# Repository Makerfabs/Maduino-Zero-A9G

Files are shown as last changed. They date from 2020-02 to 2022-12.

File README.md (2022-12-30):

# Maduino-Zero-A9G

```c++
/*
Version:		V1.0
Author:			Vincent
Create Date:	2022/12/30
Note:
	
*/
```
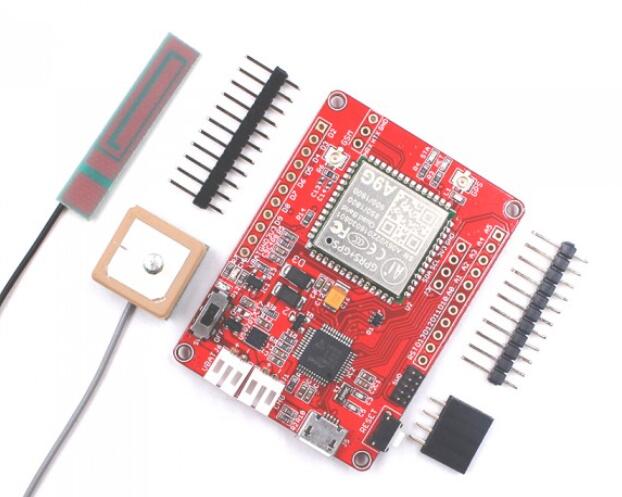
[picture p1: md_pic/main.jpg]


[toc]

# Makerfabs

[Makerfabs home page](https://www.makerfabs.com/)

[Makerfabs Wiki](https://wiki.makerfabs.com/)

# Maduino-Zero-A9G
## Intruduce

Product Link ：[Maduino Zero GPRS/GPS A9G](https://www.makerfabs.com/maduino-zero-a9g.html) 

Wiki Link : [Maduino Zero A9G](https://wiki.makerfabs.com/Maduino_Zero_A9G.html) 

Maduino Zero A9G is an IoT (Internet of things) Solution based on the 32-bit Atmel’s SAMD21 MCU and GPRS/GSM GPS module A9G. It integrates a micro Controller ATSAMD21G18, GRRS/GSM GPS module A9G, which is the upgrade version of Maduino GPRS A7, power management and storage, to make the A9G ready for a real project for IoT projects such as smart-home, outdoor monitoring, etc. The Maduino Zero A9G is based on the Arduino, users can program it with Arduino IDE, which is very easy especially suit for the none-programmers. There are also guide for users to learn how to create the first IoT project with this board, with which the starters can learn the hardware and programming skill quickly. With this board, you will easy to add text, SMS, and data to your project. It is good for your smart home project or GPS tracker and so on.

## Feature

- BAT Input Voltage: 3.4-4.2V
- ATSAMD21G18, 32-Bit ARM Cortex M0+
- Micro SIM connector
- Integrated Power Control System
- Support AT Command
- Quad-Band: 850/900/1800/1900Mz
- Support GPS
- Support GPRS data traffic, the maximum data rate, download 85.6Kbps, upload 42.8Kbps

# Code

## Compiler Options

**If you have any questions，such as how to install the development board, how to download the code, how to install the library. Please refer to :[Makerfabs_FAQ](https://github.com/Makerfabs/Makerfabs_FAQ)**

- Install board : **Arduino Zero**.
- Upload codes, select **Arduino/Genuino Zero(Native USB port)**

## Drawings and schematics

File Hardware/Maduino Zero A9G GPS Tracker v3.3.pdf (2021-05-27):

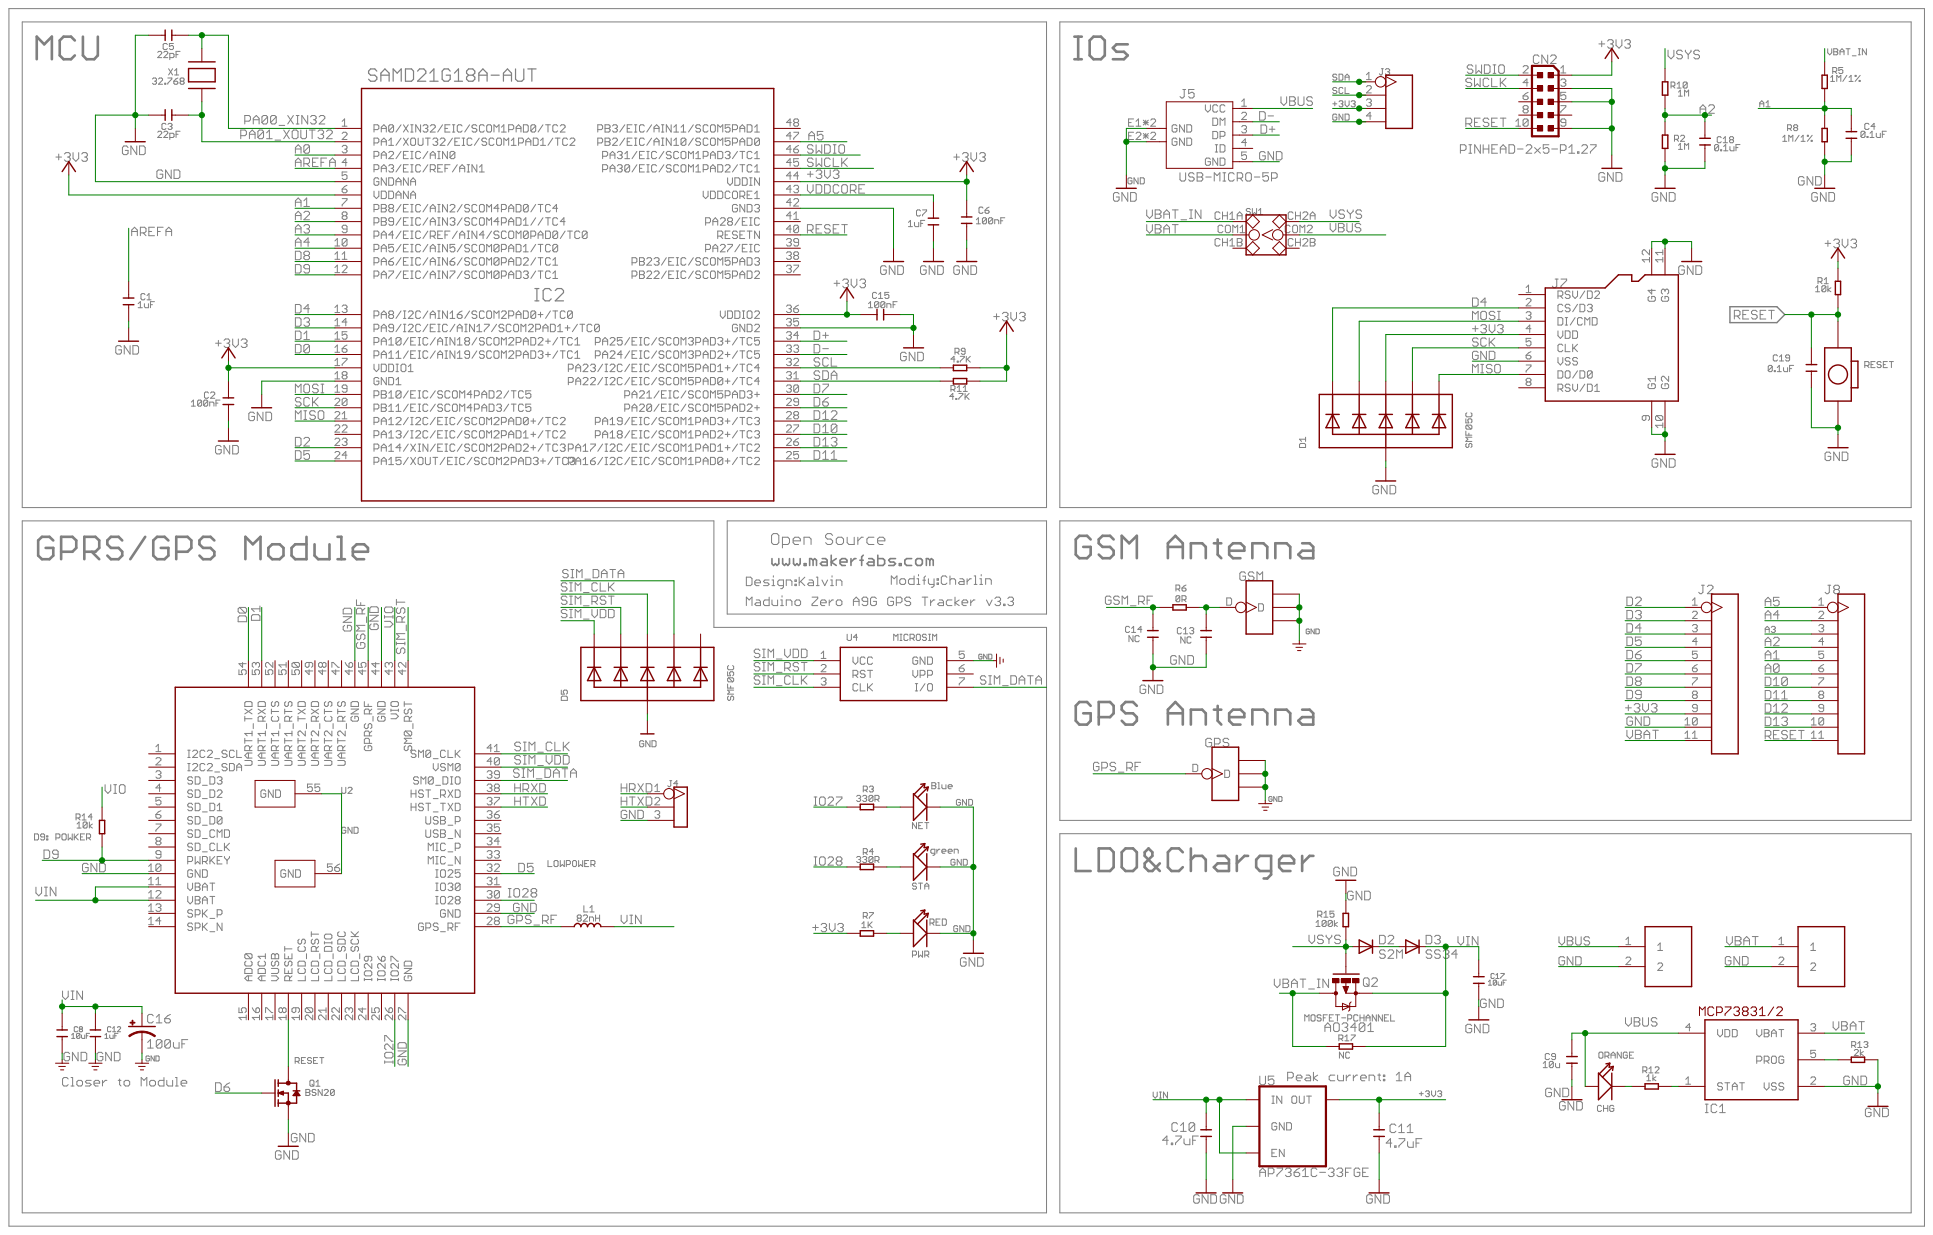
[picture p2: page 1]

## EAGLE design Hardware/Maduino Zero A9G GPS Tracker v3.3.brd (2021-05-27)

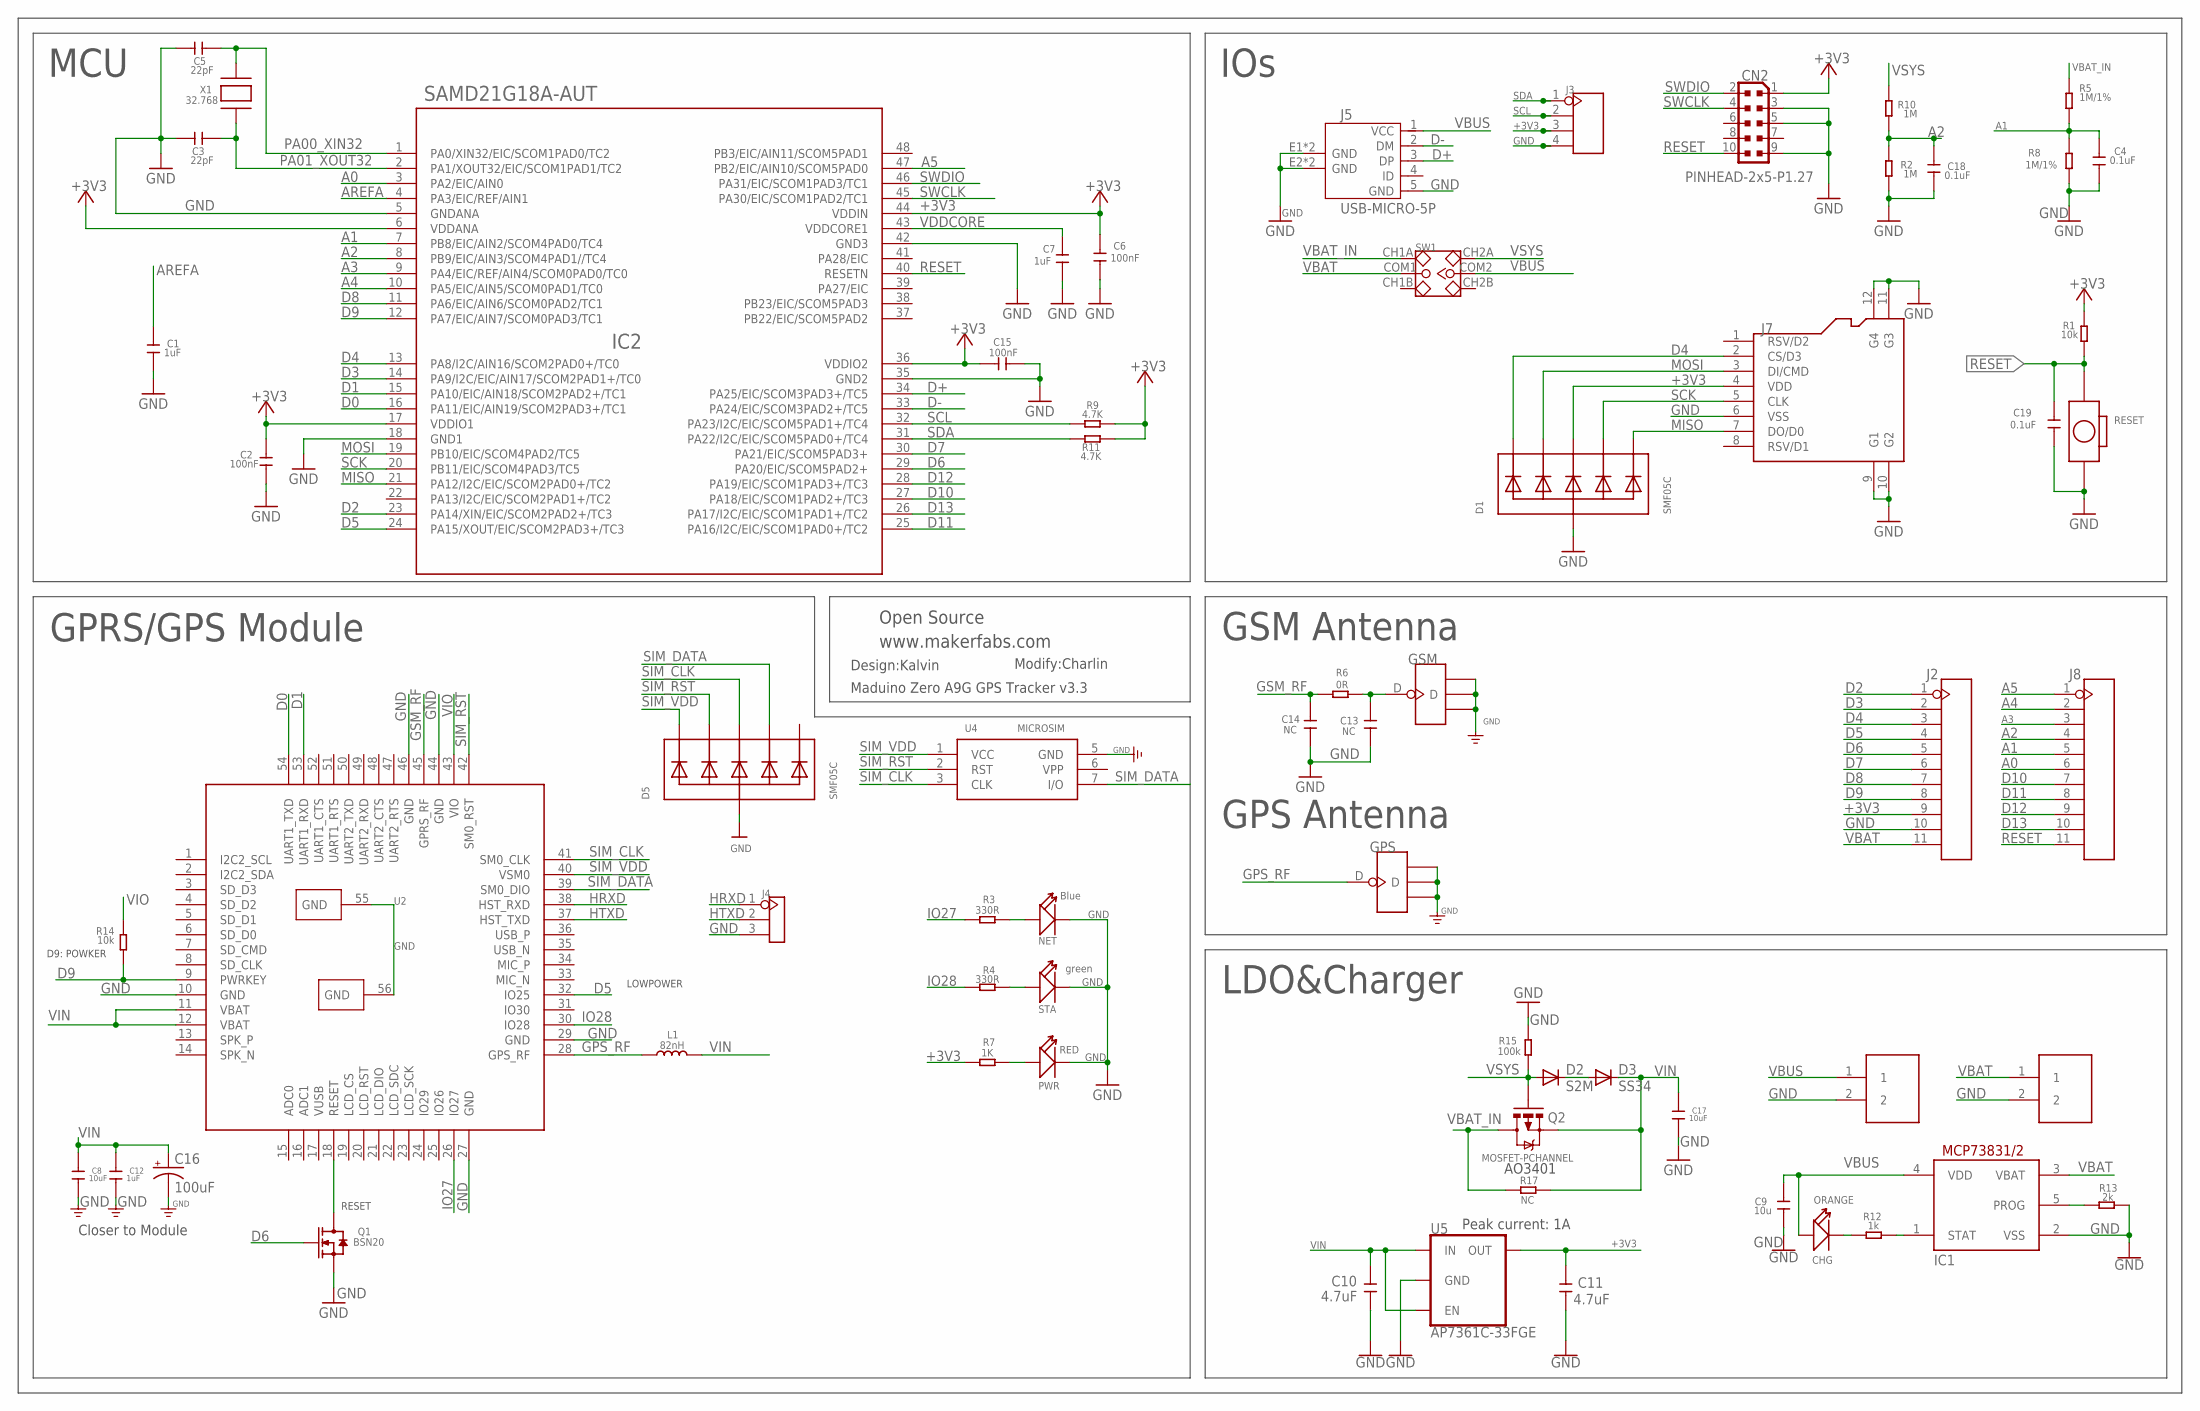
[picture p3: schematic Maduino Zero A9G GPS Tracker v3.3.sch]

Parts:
C1, C7, C12: 1uF; C0603
C2, C6, C15: 100nF; C0603
C3, C5: 22pF; C0603
C4, C18, C19: 0.1uF; C0603
C8, C17: 10uF; C0603
C9: 10u; C0603
C10, C11: 4.7uF; C0603
C13, C14: NC; C0402
C16: 100uF; EIA3528
CHG: ORANGE; D0603
CN2: PINHEAD-2x5-P1.27; PINHEAD_2X05_127
D1, D5: SMF05C; SOT363
D2: S2M; DO-214AC
D3: SS34; DO-214AC
GPS: ANTENNA-U-FL; 4P-U-FL
GSM: ANTENNA-U-FL; 4P-U-FL
IC1: MCP73831/OT; SOT23-5L
IC2: SAMD21G18A-AUT; TQFP48-7X7
J1, J6: PH2.0-2P-90-DIP
J2, J8: HEADER-11P-2.54; 11P-2.54
J3: HEADER-4P-60/35MILROUND; 4P-65/35ROUND
J4: HEADER-3P-2.54; 3P-2.54
J5: USB-MICRO-5P; MICRO-USB-5P
J7: HOLDER-MICROSD-8P; 8P-SMD
L1: 82nH; L0603
NET: Blue; LED-0603
PWR: RED; LED-0603
Q1: BSN20; SOT23@1
Q2: MOSFET-PCHANNEL; SOT23-3
R1, R14: 10k; R0603
R2, R10: 1M; R0603
R3, R4: 330R; R0603
R5, R8: 1M/1%; R0603
R6: 0R; R0603
R7: 1K; R0603
R9, R11: 4.7K; R0603
R12: 1k; R0603
R13: 2k; R0603
R15: 100k; R0603
R17: NC; R0603
RESET: BOTTON-2P-90D; 2P-7.62X3.56-90D
STA: green; LED-0603
SW1: SWITCH-2CH-6P; 6P-2CH-2.54-7.6X3.0
U2: A9G
U4: MICROSIM
U5: AP7361C-33FGE; 8-UDFN
X1: 32.768; XTAL3215

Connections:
+3V3: C2.2, C6.1, C11.2, C15.1, CN2.1, D1.4 (C3), IC2.6 (VDDANA), IC2.17 (VDDIO1), IC2.36 (VDDIO2), IC2.44 (VDDIN), J2.9, J3.3, J7.4 (VDD), R1.2, R7.1, R9.2, R11.2, U5.1 (OUT)
A0: IC2.3 (PA2/EIC/AIN0), J8.6
A1: C4.1, IC2.7 (PB8/EIC/AIN2/SCOM4PAD0/TC4), J8.5, R5.1, R8.2
A2: C18.1, IC2.8 (PB9/EIC/AIN3/SCOM4PAD1//TC4), J8.4, R2.2, R10.1
A3: IC2.9 (PA4/EIC/REF/AIN4/SCOM0PAD0/TC0), J8.3
A4: IC2.10 (PA5/EIC/AIN5/SCOM0PAD1/TC0), J8.2
A5: IC2.47 (PB2/EIC/AIN10/SCOM5PAD0), J8.1
AREFA: C1.1, IC2.4 (PA3/EIC/REF/AIN1)
D0: IC2.16 (PA11/EIC/AIN19/SCOM2PAD3+/TC1), U2.54 (UART1_TXD)
D1: IC2.15 (PA10/EIC/AIN18/SCOM2PAD2+/TC1), U2.53 (UART1_RXD)
D2: IC2.23 (PA14/XIN/EIC/SCOM2PAD2+/TC3), J2.1
D3: IC2.14 (PA9/I2C/EIC/AIN17/SCOM2PAD1+/TC0), J2.2
D4: D1.1 (C1), IC2.13 (PA8/I2C/AIN16/SCOM2PAD0+/TC0), J2.3, J7.2 (CS/D3)
D5: IC2.24 (PA15/XOUT/EIC/SCOM2PAD3+/TC3), J2.4, U2.32 (IO25)
D6: IC2.29 (PA20/EIC/SCOM5PAD2+), J2.5, Q1.1 (G)
D7: IC2.30 (PA21/EIC/SCOM5PAD3+), J2.6
D8: IC2.11 (PA6/EIC/AIN6/SCOM0PAD2/TC1), J2.7
D9: IC2.12 (PA7/EIC/AIN7/SCOM0PAD3/TC1), J2.8, R14.1, U2.9 (PWRKEY)
D10: IC2.27 (PA18/EIC/SCOM1PAD2+/TC3), J8.7
D11: IC2.25 (PA16/I2C/EIC/SCOM1PAD0+/TC2), J8.8
D12: IC2.28 (PA19/EIC/SCOM1PAD3+/TC3), J8.9
D13: IC2.26 (PA17/I2C/EIC/SCOM1PAD1+/TC2), J8.10
D+: IC2.34 (PA25/EIC/SCOM3PAD3+/TC5), J5.3 (DP)
D-: IC2.33 (PA24/EIC/SCOM3PAD2+/TC5), J5.2 (DM)
GND: C1.2, C2.1, C3.2, C4.2, C5.2, C6.2, C7.2, C8.1, C9.1, C10.1, C11.1, C12.1, C13.1, C14.1, C15.2, C16.C (-), C17.1, C18.2, C19.1, CN2.3, CN2.5, CN2.9, D1.2 (A), D5.2 (A), GPS.GND1, GPS.GND2, GPS.GND3, GSM.GND1, GSM.GND2, GSM.GND3, IC1.2 (VSS), IC2.5 (GNDANA), IC2.18 (GND1), IC2.35 (GND2), IC2.42 (GND3), J1.2, J2.10, J3.4, J4.3, J5.5 (GND), J5.E1 (GND), J5.E2 (GND), J5.P1 (GND), J5.P2 (GND), J6.2, J7.6 (VSS), J7.9 (G1), J7.10 (G2), J7.11 (G3), J7.12 (G4), NET.-, PWR.-, Q1.2 (S), R2.1, R8.1, R13.2, R15.2, RESET.P$2 (2), STA.-, U2.10 (GND), U2.27 (GND), U2.29 (GND), U2.44 (GND), U2.46 (GND), U2.55 (GND), U2.56 (GND), U4.5 (GND), U5.4 (GND), U5.EP (GND)
GPS_RF: GPS.D, L1.1, U2.28 (GPS_RF)
GSM_RF: C14.2, R6.1, U2.45 (GPRS_RF)
HRXD: J4.1, U2.38 (HST_RXD)
HTXD: J4.2, U2.37 (HST_TXD)
IO27: R3.1, U2.26 (IO27)
IO28: R4.1, U2.30 (IO28)
MISO: D1.6 (C5), IC2.21 (PA12/I2C/EIC/SCOM2PAD0+/TC2), J7.7 (DO/D0)
MOSI: D1.3 (C2), IC2.19 (PB10/EIC/SCOM4PAD2/TC5), J7.3 (DI/CMD)
unnamed: R4.2, STA.+
unnamed: D2.C, D3.A
unnamed: PWR.+, R7.2
unnamed: NET.+, R3.2
unnamed: Q1.3 (D), U2.18 (RESET)
unnamed: CHG.-, R12.1
unnamed: IC1.1 (STAT), R12.2
unnamed: IC1.5 (PROG), R13.1
unnamed: C13.2, GSM.D, R6.2
PA00_XIN32: C5.1, IC2.1 (PA0/XIN32/EIC/SCOM1PAD0/TC2), X1.P$2
PA01_XOUT32: C3.1, IC2.2 (PA1/XOUT32/EIC/SCOM1PAD1/TC2), X1.P$1
RESET: C19.2, CN2.10, IC2.40 (RESETN), J8.11, R1.1, RESET.P$1 (1)
SCK: D1.5 (C4), IC2.20 (PB11/EIC/SCOM4PAD3/TC5), J7.5 (CLK)
SCL: IC2.32 (PA23/I2C/EIC/SCOM5PAD1+/TC4), J3.2, R9.1
SDA: IC2.31 (PA22/I2C/EIC/SCOM5PAD0+/TC4), J3.1, R11.1
SIM_CLK: D5.4 (C3), U2.41 (SM0_CLK), U4.3 (CLK)
SIM_DATA: D5.5 (C4), U2.39 (SM0_DIO), U4.7 (I/O)
SIM_RST: D5.3 (C2), U2.42 (SM0_RST), U4.2 (RST)
SIM_VDD: D5.1 (C1), U2.40 (VSM0), U4.1 (VCC)
SWCLK: CN2.4, IC2.45 (PA30/EIC/SCOM1PAD2/TC1)
SWDIO: CN2.2, IC2.46 (PA31/EIC/SCOM1PAD3/TC1)
VBAT: IC1.3 (VBAT), J2.11, J6.1, SW1.COM1
VBAT_IN: Q2.3 (D), R5.2, R17.1, SW1.CH1A
VBUS: C9.2, CHG.+, IC1.4 (VDD), J1.1, J5.1 (VCC), SW1.COM2
VDDCORE: C7.1, IC2.43 (VDDCORE1)
VIN: C8.2, C10.2, C12.2, C16.A (+), C17.2, D3.C, L1.2, Q2.2 (S), R17.2, U2.11 (VBAT), U2.12 (VBAT), U5.5 (EN), U5.8 (IN)
VIO: R14.2, U2.43 (VIO)
VSYS: D2.A, Q2.1 (G), R10.2, R15.1, SW1.CH2A

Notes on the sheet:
GSM Antenna
GPRS/GPS Module
LOWPOWER
RESET
D9: POWKER
Peak current: 1A
www.makerfabs.com
MCU
IOs
LDO&Charger
GPS Antenna
Design:Kalvin
Modify:Charlin
Open Source
Closer to Module
AO3401
Maduino Zero A9G GPS Tracker v3.3

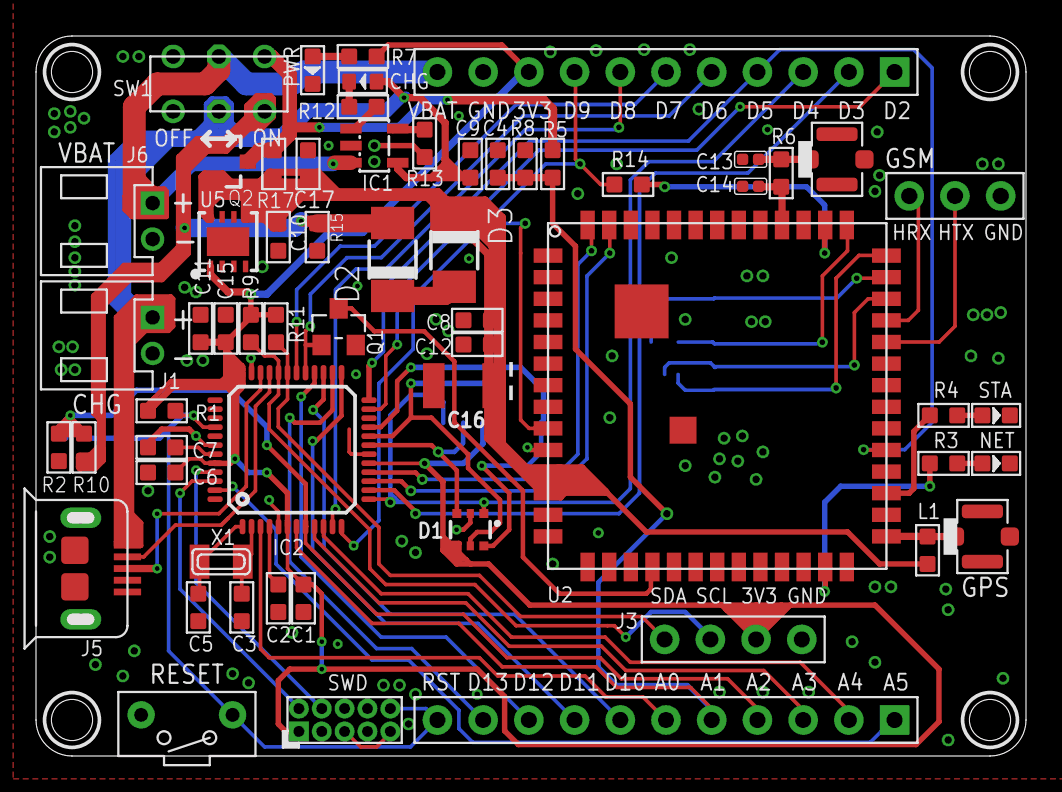
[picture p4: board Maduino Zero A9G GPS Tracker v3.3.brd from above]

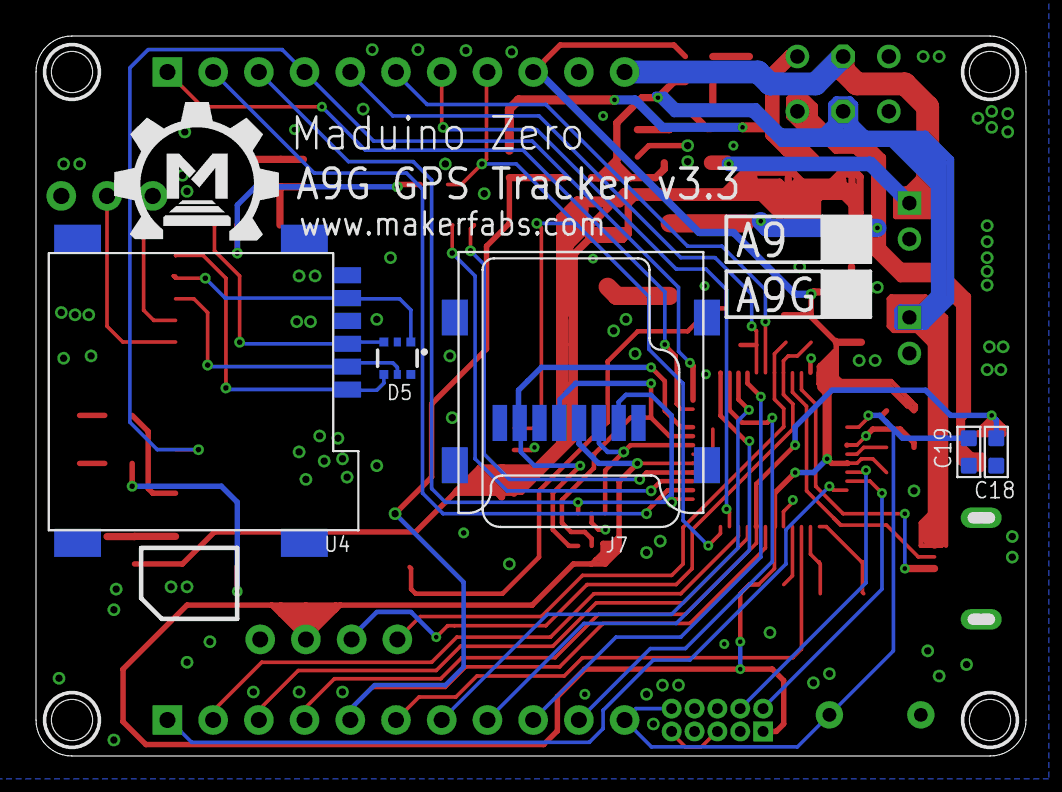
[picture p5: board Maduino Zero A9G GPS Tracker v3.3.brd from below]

Board: 2 copper layers, 55.0 x 40.0 mm, 66 parts (6 on the bottom side), 61 nets.

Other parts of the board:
U$1: MAKERFABS_0.3

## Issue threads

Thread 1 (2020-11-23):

The board behaviour is not well documented!

tontonialberto, 2020-11-23:
int pon=9;
  int poff=6;
  int lowp=5;

Do you mean that i can't use D9,D6, and D5 for other purposes?

tontonialberto, 2020-11-23:
In addition, please write meaningful comments into the sketches. Some of the implementation details are really not explained.

kaandemirtas, 2021-04-26:
Which pins are available to use for other purposes when using both GPRS and GPS functions? I would like to drive an I2C oled display and also a stepper motor. Is that possible?

tontonialberto, 2021-04-27:
Hello @kaandemirtas ,
AFAIK you _should_ not use pins 5, 6, and 9, because they're used for A9G power management.
However, if you must stick with these hobbyist boards, I would recommend the Maduino Zero SIM808, just because the SIM808 has far better documentation than the Chinese-only A9G.

Best regards

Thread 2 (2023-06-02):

A9G Maduino Zero

mike1739, 2023-06-02:
/A9G_AT_Commands_Test.ino)
Using this sketch I am able to see GPS data etc not a problem.  My next sketch to include GSM fails miserably using .......
https://how2electronics.com/gps-gsm-based-vehicle-tracking-system-using-arduino/  tutorial from How2
All I ever see is stuff like CME Error 52  or NO SIM ?
Rgds Mike

mike1739, 2023-06-02:
PS this is the code ..
// https://www.makerfabs.cc/article/diy-gps-gsm-vehicle-tracking-system-on-maduino.html

#include<string.h>

#define DEBUG true

int PWR_KEY = 9;
int RST_KEY = 6;
int LOW_PWR_KEY = 5;

String msg = String("");
int SmsContentFlag = 0;
String mob;
String loct;
void setup()
{
  pinMode(PWR_KEY, OUTPUT);
  pinMode(RST_KEY, OUTPUT);
  pinMode(LOW_PWR_KEY, OUTPUT);
  digitalWrite(RST_KEY, LOW);
  digitalWrite(LOW_PWR_KEY, HIGH);
  digitalWrite(PWR_KEY, HIGH);

  //      String msg = String("");
  //    int SmsContentFlag = 0;

  SerialUSB.begin(9600);
  Serial1.begin(9600);
  //modulePowerOn();
  delay(2000);
  SerialUSB.println("Checking Module...");
  int i = 1;
  String res;
  while (i) {
    Serial1.println("AT");
    while (Serial1.available() > 0) {
      if (Serial1.find("OK"))
        i = 0;
    }
    delay(500);
  }
  SerialUSB.println("Module Connected");
  //GprsTextModeSMS();
  SerialUSB.print("Text Mode: ");
  i = 1;
  while (i) {
    Serial1.println("AT+CMGF=1\r");
    while (Serial1.available() > 0) {
      if (Serial1.find("OK"))
        i = 0;
    }
    delay(500);
  }
  SerialUSB.println("ON");
  Serial1.println("AT+GPS=1");
  SerialUSB.println("GPS Intializing...");
  delay(5000);
  SerialUSB.println("GPS Initialized");
  SerialUSB.flush();
  i = 1;
  String str;
  while (i) {
    Serial1.println("AT+LOCATION=2");
    delay(100);
    while (Serial1.available() <= 0);
    if (Serial1.find("AT+LOCATION=2")) {
      str = Serial1.readString();
      //SerialUSB.println(str);
      i = 0;
    }
    delay(500);
  }
  loct = str.substring(4, 23);
  SerialUSB.print("Location: ");
  SerialUSB.println(loct);
  //while(1);
  SerialUSB.println("Send sms to get the location");
}

void loop()
{
  char SerialInByte;

  if (Serial1.available())
  {
    //char SerialInByte;
    SerialInByte = (unsigned char)Serial1.read();
    if ( SerialInByte == 13 ) //0x0D
    {
      ProcessGprsMsg();
    }
    if ( SerialInByte == 10 )
    {
    }
    else
    {
      //EN: store the current character in the message string buffer
      msg += String(SerialInByte);
    }
  }
  if (SmsContentFlag == 1) {
    int i;
    SerialUSB.println("Flag Cleared");
    SerialUSB.print("Message: ");
    SerialUSB.println(msg);
    if (msg.indexOf("Location")) {
      SerialUSB.println("Message Received");
      i = msg.indexOf("+91");
      //SerialUSB.print("index: ");
      //SerialUSB.println(i);
      //SerialUSB.println(msg[i+1]);
      i = i + 3;
      for (int j = 0; j < 10; j++, i++) {
        mob += msg[i];
      }
      SerialUSB.print("Mobile: ");
      SerialUSB.println(mob);
      String cmd = "AT+CMGS=\"";
      cmd += mob;
      cmd += "\"";
      cmd += "\r";
      Serial1.println(cmd);
      delay(100);

      Serial1.print("Your Vehicle Current Location ");
      Serial1.print(loct);
      Serial1.print("\n");
      Serial1.print("Check Map: \n");
      Serial1.print(" https://www.google.com/maps/@");
      Serial1.println(loct);
      Serial1.println((char)26);
      delay(1000);
    }
    ClearGprsMsg();
    SmsContentFlag = 0;
    msg.remove(0);
    mob.remove(0);
  }
  delay(100);
}

// EN: Request Text Mode for SMS messaging
void GprsTextModeSMS()
{
  Serial1.println( "AT+CMGF=1" );
}

void GprsReadSmsStore( String SmsStorePos )
{
  // Serial.print( "GprsReadSmsStore for storePos " );
  // Serial.println( SmsStorePos );
  Serial1.print( "AT+CMGR=" );
  Serial1.println( SmsStorePos );
}

// EN: Clear the GPRS shield message buffer
void ClearGprsMsg()
{
  msg = "";
}

// EN: interpret the GPRS shield message and act appropiately
void ProcessGprsMsg()
{
  SerialUSB.println("");
  //  Serial.print( "GPRS Message: [" );
  SerialUSB.print( msg );
  //    Serial.println( "]" );
  if ( msg.indexOf( "Call Ready" ) >= 0 )
  {
    SerialUSB.println( "*** GPRS Shield registered on Mobile Network ***" );
    GprsTextModeSMS();
  }

  //EN: unsolicited message received when getting a SMS message
  if ( msg.indexOf( "+CIEV" ) >= 0 )
  {
    SerialUSB.println( "*** SMS Received ***" );
  }

  //EN: SMS store readed through UART (result of GprsReadSmsStore request)
  if ( msg.indexOf( "+CMT:" ) >= 0 )
  {
    // EN: Next message will contains the BODY of SMS
    SmsContentFlag = 1;
    // EN: Following lines are essentiel to not clear the flag!
    //ClearGprsMsg();
    return;
  }

  // EN: +CMGR message just before indicate that the following GRPS Shield message
  //     (this message) will contains the SMS body
  if ( SmsContentFlag == 1 )
  {
    SerialUSB.println( "*** SMS MESSAGE CONTENT ***" );
    SerialUSB.println( msg );
    SerialUSB.println( "*** END OF SMS MESSAGE ***" );
    //ProcessSms( msg );
  }

  /*ClearGprsMsg();
    //EN: Always clear the flag
    SmsContentFlag = 0; */
}

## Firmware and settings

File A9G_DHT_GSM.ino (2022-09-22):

#include <stdio.h>
#include <string.h>

#include <DHT.h>
#include <DHT_U.h>

//*******for senser **********
float humidity;//humidity
float temperature;//temperature

#define DHTPIN 3    //D3
#define DHTTYPE DHT11 
DHT dht(DHTPIN, DHTTYPE);


//Description: GSM Test for A9 or A9G, show the humidity and temperature on the Internet.
//version:v1.0
//Date:2019/11/26
//Author:Charlin
//web: http://www.makerfabs.com

//  https://thingspeak.com/channels/920821


void(* resetFunc) (void) = 0; //declare reset function at address 0

#define DEBUG true
int PWR_KEY = 9;
int RST_KEY = 6;
int LOW_PWR_KEY = 5;

bool ModuleState=false;
unsigned long timeCount;

//**********api write key******************
const String apiKey="P310JKLFLCY7B09G";

String  showString="";

void setup()
{

    pinMode(PWR_KEY, OUTPUT);
    pinMode(RST_KEY, OUTPUT);
    pinMode(LOW_PWR_KEY, OUTPUT);
    digitalWrite(RST_KEY, LOW);
    digitalWrite(LOW_PWR_KEY, HIGH);
    digitalWrite(PWR_KEY, HIGH);
    Serial1.begin(115200);
    digitalWrite(PWR_KEY, LOW);
    delay(3000);
    digitalWrite(PWR_KEY, HIGH);
    delay(10000);
    
    SerialUSB.begin(115200);
    SerialUSB.println("Hello, Maduino!");
    SerialUSB.println("There need some time to initialize!");
    delay(16000);

    dht.begin();//sensor begin
    humidity = dht.readHumidity();
    temperature = dht.readTemperature();

    Serial1.begin(115200);
    
    //while (!SerialUSB)
    {
        ;// wait for serial port to connect
    }


    ModuleState=moduleStateCheck();
    if(ModuleState==false)//if it's off, turn on it.
    {
      digitalWrite(PWR_KEY, LOW);
      delay(3000);
      digitalWrite(PWR_KEY, HIGH);
      delay(10000);
      SerialUSB.println("Now turnning the A9/A9G on.");
    }
 
#if 1
    //GPS test
    sendData("AT+GPS=0", 1000, DEBUG);//1: turn on GPS  0:Turn off GPS
    //sendData("AT+GPSRD=10", 1000, DEBUG);//Read NEMA information every 10 seconds 
    //sendData("AT+LOCATION=2", 1000, DEBUG);//AT+LOCATION=X  //1:Get base address, 2:get gps address

    //GSM Test
    sendData("AT+CCID", 3000, DEBUG);  //get SIM 
    sendData("AT+CREG?", 3000, DEBUG);
    sendData("AT+CGATT=1", 1000, DEBUG);
    
    sendData("AT+CGDCONT=1,\"IP\",\"CMNET\"", 1000, DEBUG);
    sendData("AT+CGACT=1,1", 1000, DEBUG);

    sendData("AT+CSQ", 1000, DEBUG);  //
    //sendData("AT+CIPSTART=\"TCP\",\"www.makerfabs.com\",80", 2000, DEBUG);//


    String cmdString= "AT+HTTPGET=\"http://api.thingspeak.com/update.json?api_key=" + apiKey + "&field1=" + (String)temperature +"&field2=" + (String)humidity + "&field3=0.0&field4=0.0" + "\"";
    sendData(cmdString,5000,DEBUG);
#endif
  
  timeCount=millis();
  SerialUSB.println("Maduino A9/A9G Test Begin!");
}

void loop()
{

#if 1
  if(millis()-timeCount>30000) //60000ms
  {
    
    humidity = dht.readHumidity();
    temperature = dht.readTemperature();
    
    SerialUSB.println("humidity is " + (String)humidity);
    SerialUSB.println("temperature is " + (String)temperature);

  //if (!isnan(humidity) && !isnan(temperature)) 
  {
    //SerialUSB.println("Read from DHT sensor!");
    //showString = "Humidity:" + (String)humidity + "%" + "\r\n" +"Temperature:"+(String)temperature + "C"; 
  }
    //SerialUSB.println(showString);

    //sendData("AT+CGATT=1", 1000, DEBUG);
    //sendData("AT+CGACT=1,1", 1000, DEBUG);
    //sendData("AT+CGDCONT=1,\"IP\",\"CMNET\"", 1000, DEBUG);

  String cmdString= "AT+HTTPGET=\"http://api.thingspeak.com/update.json?api_key=" + apiKey + "&field1=" + (String)temperature +"&field2=" + (String)humidity + "&field3=0.0&field4=0.0" + "\"";
    //SerialUSB.println(cmdString);
    sendData(cmdString,5000,DEBUG);
    //delay(5000);
    timeCount=millis();//refresh
  }
#endif

  while (Serial1.available() > 0) {
    String cstring = Serial1.readString();
    SerialUSB.print(cstring);//SerialUSB.write(Serial1.read());
    yield();
 
  }
  while (SerialUSB.available() > 0) {
    Serial1.write(SerialUSB.read());
    yield();
  }
}

bool moduleStateCheck()
{
    int i = 0;
    bool state=false;
    for (i = 0; i < 10; i++)
    {
        String msg = String("");
        msg = sendData("AT", 1000, DEBUG);
        if (msg.indexOf("OK") >= 0)
        {
            SerialUSB.println("A9/A9G Module had turned on.");
        		state=true;
            return state;
        }
        delay(500);
    }
  	return state;
}

String sendData(String command, const int timeout, boolean debug)
{
    String response = "";
    Serial1.println(command);
    long int time = millis();
    while ((time + timeout) > millis())
    {
        while (Serial1.available())
        {
            char c = Serial1.read();
            response += c;
        }
    }
    if (debug)
    {
        SerialUSB.print(response);
    }
    return response;
}

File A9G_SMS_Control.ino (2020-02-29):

#include<stdio.h>
#include<string.h>

//Description: A9 or A9G SMS test: send message to control the board to turn on/off R/G/B LED.
//version:v1.0
//Date:2020/02/28
//
//Modified by:Charlin
//WEB: http://www.makerfabs.com
//SIM Card must support SMS Service



#define DEBUG true

int PWR_KEY=9;
int RST_KEY=6;
int LOW_PWR_KEY=5;

int LED_R	= 2;  //D2	RED
int LED_G = 3;	//D3	GREEN
int LED_B	=	4;	//D4	BLUE

String msg = String("");
int SmsContentFlag = 0;

void setup()
{

	  pinMode(PWR_KEY, OUTPUT);
	  pinMode(RST_KEY, OUTPUT);
	  pinMode(LOW_PWR_KEY, OUTPUT);
	  digitalWrite(RST_KEY, LOW);
	  digitalWrite(LOW_PWR_KEY, HIGH);   
	  digitalWrite(PWR_KEY, HIGH);

	  pinMode(LED_R, OUTPUT); 
	  pinMode(LED_G, OUTPUT);
	  pinMode(LED_B, OUTPUT);
	  digitalWrite(LED_R, HIGH);
	  digitalWrite(LED_G, HIGH);
	  digitalWrite(LED_B, HIGH);
	  
//		String msg = String("");
//	  int SmsContentFlag = 0;

	  SerialUSB.begin(115200);
		while (!SerialUSB) {
	    ; // wait for Arduino serial port to connect
	  }
	  Serial1.begin(115200);
		modulePowerOn();
	  GprsTextModeSMS();
}

void loop()
{
		char SerialInByte;
    if(SerialUSB.available())
    {
        Serial1.print((unsigned char) SerialUSB.read());
    }  
    else if(Serial1.available())
    {
        //char SerialInByte;
        SerialInByte = (unsigned char)Serial1.read();
        if( SerialInByte == 13 )//0x0D
        {
          ProcessGprsMsg();
				}
				if( SerialInByte == 10 )
				{
        }
				else
				{
           //EN: store the current character in the message string buffer
           msg += String(SerialInByte);
        }
     }
}
 
void modulePowerOn()
{
		int i=0;
		boolean result = false;
		digitalWrite(PWR_KEY, LOW);    
    delay(3000); 
    digitalWrite(PWR_KEY, HIGH);
    delay(15000); 

		result =  Serial1.find("OK");
		if(result)
			SerialUSB.println( "Please send sms to control your device!" );
    else
		{
				for(i=0;i<10;i++)
				{
						Serial1.println("AT");
						delay(500);
						result =  Serial1.find("OK");
						if(result)
						{
								SerialUSB.println( "Please send sms to control your device!" );
								return;
						}
         }
		}
}

void ProcessSms( String sms )
{
		SerialUSB.print( "ProcessSms for [" );
		SerialUSB.print( sms );
		SerialUSB.println( "]" ); 
		if( sms.indexOf("onr") >= 0)
		{
    		digitalWrite(LED_R, LOW);
				SerialUSB.println( "LED Red ON" );
				//return;
		}
		if( sms.indexOf("ong") >= 0)
		{
				digitalWrite( LED_G, LOW);
				SerialUSB.println( "LED Green ON");
				//return;
		}
    if( sms.indexOf("onb") >= 0 )
    {
    		digitalWrite(LED_B, LOW);
     		SerialUSB.println( "LED Blue ON" );
				//return;
		}
    if( sms.indexOf("offr") >= 0 )
    {
				digitalWrite(LED_R,HIGH);
				SerialUSB.println( "LED Red OFF" );
				//return;
		}
		if(sms.indexOf("offg") >= 0 )
		{
				digitalWrite(LED_G, HIGH );
				SerialUSB.println( "LED Green OFF" );
				//return;
		}
    if( sms.indexOf("offb") >= 0 )
		{
				digitalWrite(LED_B, HIGH );
				SerialUSB.println( "LED Blue OFF" );
				//return;
		}
}

// EN: Request Text Mode for SMS messaging
void GprsTextModeSMS()
{
		Serial1.println( "AT+CMGF=1" );
}

void GprsReadSmsStore( String SmsStorePos )
{
		// Serial.print( "GprsReadSmsStore for storePos " );
		// Serial.println( SmsStorePos ); 
		Serial1.print( "AT+CMGR=" );
		Serial1.println( SmsStorePos );
}
 
// EN: Clear the GPRS shield message buffer
void ClearGprsMsg()
{
		msg = "";
}
 
// EN: interpret the GPRS shield message and act appropiately
void ProcessGprsMsg() 
{
		SerialUSB.println("");
		//  Serial.print( "GPRS Message: [" );
		SerialUSB.print( msg );
		//    Serial.println( "]" );
		if( msg.indexOf( "Call Ready" ) >= 0 )
		{
				SerialUSB.println( "*** GPRS Shield registered on Mobile Network ***" );
				GprsTextModeSMS();
		}
 
		//EN: unsolicited message received when getting a SMS message
		if( msg.indexOf( "+CIEV" ) >= 0 )
		{
				SerialUSB.println( "*** SMS Received ***" );
		}
 
		//EN: SMS store readed through UART (result of GprsReadSmsStore request)  
		if( msg.indexOf( "+CMT:" ) >= 0 )
		{
				// EN: Next message will contains the BODY of SMS
				SmsContentFlag = 1;
				// EN: Following lines are essentiel to not clear the flag!
				ClearGprsMsg();
				return;
		}
 
		// EN: +CMGR message just before indicate that the following GRPS Shield message 
		//     (this message) will contains the SMS body
		if( SmsContentFlag == 1 )
		{
				SerialUSB.println( "*** SMS MESSAGE CONTENT ***" );
				SerialUSB.println( msg );
				SerialUSB.println( "*** END OF SMS MESSAGE ***" );
				ProcessSms( msg );
		}
 
		ClearGprsMsg();
		//EN: Always clear the flag
		SmsContentFlag = 0; 
}

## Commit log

2019-11-26 v1.0
    show the temperature and humidity on OLED
2020-02-29 v1.0
    Send message to the board to control LED
2021-05-27 Hardware
    add hardware
    [Maduino Zero A9G GPS Tracker v3.3.brd, Maduino Zero A9G GPS Tracker v3.3.sch]

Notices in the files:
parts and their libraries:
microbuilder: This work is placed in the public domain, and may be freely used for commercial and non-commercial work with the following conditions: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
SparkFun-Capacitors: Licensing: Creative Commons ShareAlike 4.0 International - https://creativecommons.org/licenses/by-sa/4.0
